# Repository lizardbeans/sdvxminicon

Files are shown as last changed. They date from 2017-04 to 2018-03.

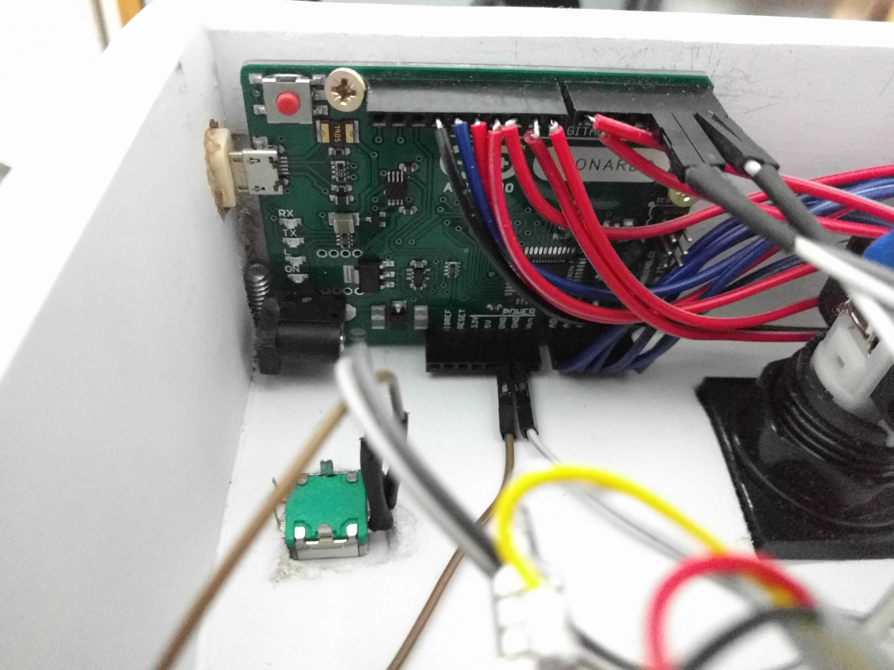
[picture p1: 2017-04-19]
img/027.jpg

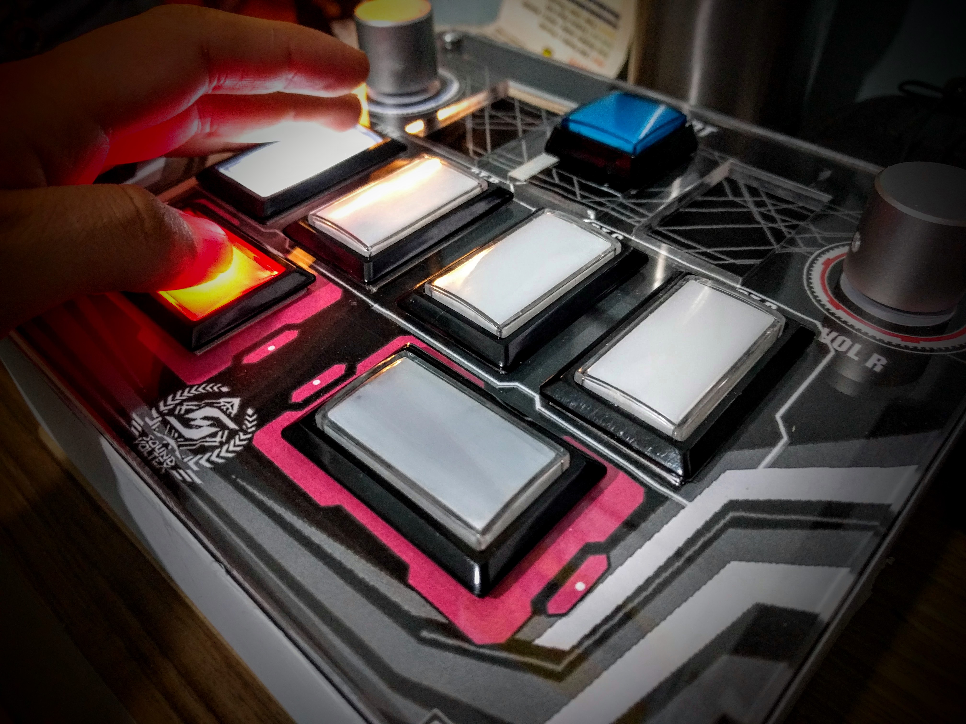
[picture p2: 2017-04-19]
img/032.jpg

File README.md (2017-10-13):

# sdvxminicon
**Instructions here: http://consandstuff.github.io/rhythmcons/sound-voltex/sdvx-minicon/**

Minicon Gallery http://imgur.com/a/BgS4V

The code is a modified version of this github repository:https://github.com/4yn/iivx

Upload using Arduino IDE 1.8.3

Tested only with 24ppr encoders.

## Part List

- 5mm laser cut clear acrylic $10-15
- 6pcs. 50x30mm chinese beatmania buttons $15 (led and switch included)
- 1pc. 30x30mm start buton $3 (led and switch included)
- 2pcs. cheap rotary encoder (24ppr) $10
- 2pcs. 22x20mm aluminum knobs $16
- 1pc. 50x50cm 5mm MDF plank (box walls) $2
- 1pc. 50x50cm 3mm MDF plank (box top and bottom door) $1
- 1pc. Arduino Leonardo PCB $18
- jumper wires pack $5
- 7pcs. crimp connectors $2 
- 2pcs. metal hinge $1 (for the door)
- 2pcs. magnetic lock $2 (for the door)
- 2pcs. 100 sandpaper $2
- 2pcs. 180 sandpaper $2

subtotal: $87

Want to change to SANWA buttons?
Add 6 12 dollar buttons instead of the chinese buttons.
Total: $144

Optional:
- 1pc. spray paint can $15 (matte white)

Tools:
- electric jigsaw
- electric sander
- electric drill

Skills:
- drilling- jigsaw-ing
- sanding
- soldering

**PIN LAYOUT (LEONARDO ARDUINO)**

<table><thead>
<tr>
<th>Button</th>
<th style="text-align: center">Pin #</th>
<th style="text-align: center">Button #</th>
<th style="text-align: center">LED Pin #</th>
</tr>
</thead><tbody>
<tr>
<td>Start</td>
<td style="text-align: center">13</td>
<td style="text-align: center">Button 1</td>
<td style="text-align: center">6</td>
</tr>
<tr>
<td>BT-A</td>
<td style="text-align: center">A0</td>
<td style="text-align: center">Button 2</td>
<td style="text-align: center">7</td>
</tr>
<tr>
<td>FX-L</td>
<td style="text-align: center">A1</td>
<td style="text-align: center">Button 3</td>
<td style="text-align: center">8</td>
</tr>
<tr>
<td>BT-B</td>
<td style="text-align: center">A2</td>
<td style="text-align: center">Button 4</td>
<td style="text-align: center">9</td>
</tr>
<tr>
<td>BT-C</td>
<td style="text-align: center">A3</td>
<td style="text-align: center">Button 5</td>
<td style="text-align: center">10</td>
</tr>
<tr>
<td>FX-R</td>
<td style="text-align: center">A4</td>
<td style="text-align: center">Button 6</td>
<td style="text-align: center">11</td>
</tr>
<tr>
<td>BT-D</td>
<td style="text-align: center">A5</td>
<td style="text-align: center">Button 7</td>
<td style="text-align: center">12</td>
</tr>
</tbody></table>

<table><thead>
<tr>
<th>ENCODERS</th>
<th style="text-align: center">DATA 1</th>
<th style="text-align: center">DATA 2</th>
</tr>
</thead><tbody>
<tr>
<td>Left knob (VOL-L)
<td style="text-align: center">0</td>
<td style="text-align: center">1</td>
</tr>
<tr>
<td>Right knob (VOL-R)
<td style="text-align: center">2</td>
<td style="text-align: center">3</td>
</tr>
</tbody></table>

>**If you're using 600ppr encoders you have to connect the encoders to the 5V pin for the 5v input (usually is the red wire)**

Any questions, troubleshooting or tips? Try my Discord server:

https://discord.gg/fknwz8s

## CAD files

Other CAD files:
cad/MINICON - Box.dwg
cad/MINICON - Acrylic 5mm.dwg

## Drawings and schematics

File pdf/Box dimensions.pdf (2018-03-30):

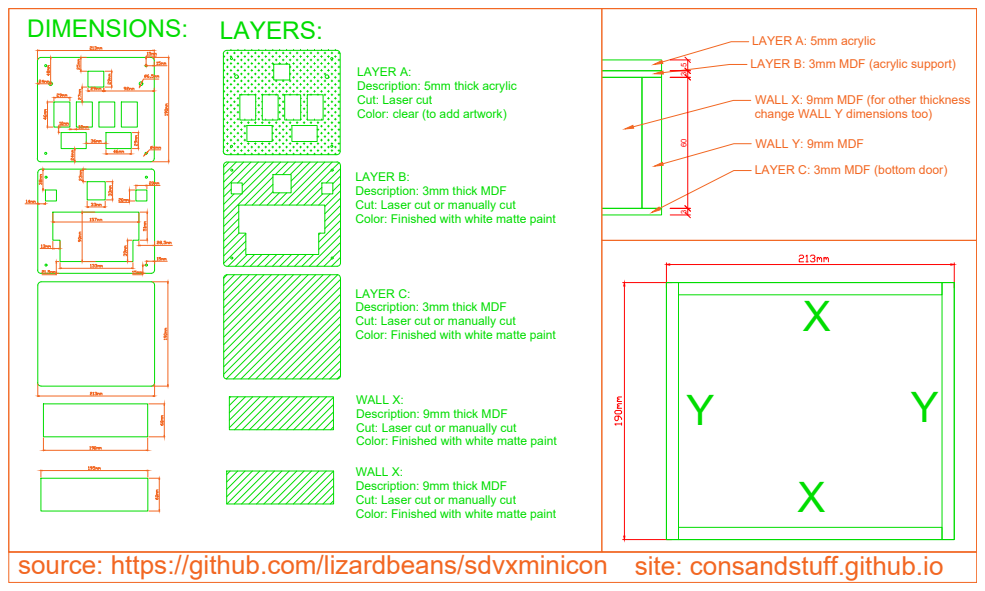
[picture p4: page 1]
LAYERS:; LAYER A: Description: 5mm thick acrylic Cut: Laser cut Color: clear (to add artwork) LAYER B: Description: 3mm thick MDF; Color: Finished with white matte paint DIMENSIONS:; LAYER A: 5mm acrylic LAYER B: 3mm MDF (acrylic support) WALL X: 9mm MDF (for other thickness change WALL Y dimensions too) WALL Y: 9mm MDF LAYER C: 3mm MDF (bottom door) 5 3 60 3 Y; Y XX source: https://github.com/lizardbeans/sdvxminicon site: consandstuff.github.io

Cut: Laser cut or manually cut
Color: Finished with white matte paint LAYER C: Description: 3mm thick MDF

Color: Finished with white matte paint WALL X: Description: 9mm thick MDF

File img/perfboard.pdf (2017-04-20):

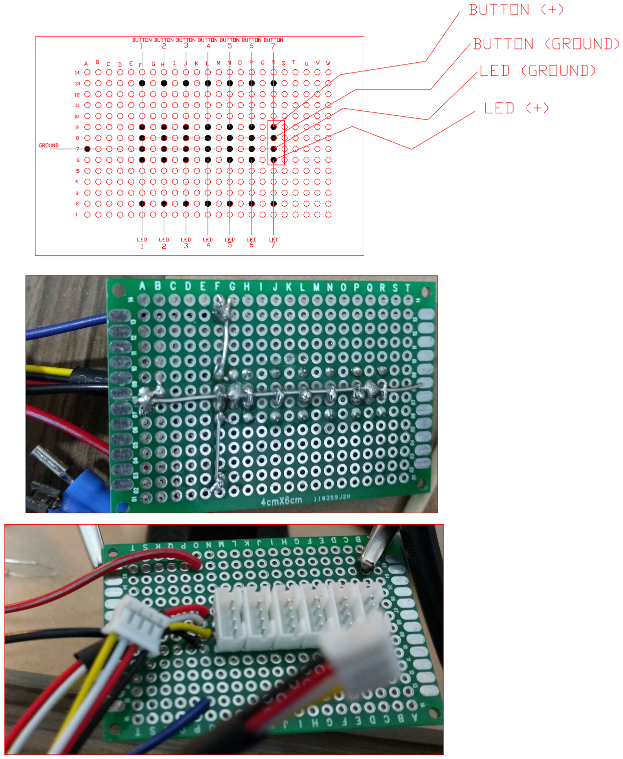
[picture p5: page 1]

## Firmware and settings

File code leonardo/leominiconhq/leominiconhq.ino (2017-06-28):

#include "iivx_leo.h"
iivxReport_t report; 

#define REPORT_DELAY 2000
// Number of microseconds between HID reports
// 2000 = 500hz

#define ENC_L_A 0
#define ENC_L_B 1
#define ENC_L_B_ADDR 3
#define ENC_R_A 2
#define ENC_R_B 3
#define ENC_R_B_ADDR 0
#define ENCODER_SENSITIVITY (double) 2.34375
#define ENCODER_PORT PIND
// encoder sensitivity = number of positions per rotation (600/256) / number of positions for HID report (256)
/*
 * connect encoders
 * VOL-L to pins 0 and 1
 * VOL-R to pins 2 and 3
 */

int tmp;
uint8_t buttonCount = 7;
uint8_t lightMode = 0;
// 0 = reactive lighting, 1 = HID lighting
uint8_t ledPins[] = {6,7,8,9,10,11,12};
uint8_t buttonPins[] = {13,18,19,20,21,22,23};
uint8_t sysPin = 5;
uint8_t reactiveLightPin = 21;
uint8_t hidLightPin = 22;
uint8_t sysInputPins[] = {13,18,19,20};
int32_t encL=0, encR=0;
/* current pin layout
 *  pins 6 to 12 = LED 1 to 7
 *  pins 13, A0 to A5 = Button input 1 to 7
 *  pins 5 = system pin
 *    connect system pin to ground with a small button
 *      press together with other buttons to change lighting scheme
 *    system button + button 1 = reactive lighting
 *    system button + button 3 = HID lighting
 */
 

void doEncL(){
  if((ENCODER_PORT >> ENC_L_B_ADDR)&1){
    encL++;
  } else {
    encL--;
  }
}

void doEncR(){
  if((ENCODER_PORT >> ENC_R_B_ADDR)&1){
    encR++;
  } else {
    encR--;
  }
}

void lights(uint8_t lightDesc){
  for(int i=0;i<buttonCount;i++){
     if((lightDesc>>i)&1){
         digitalWrite(ledPins[i],HIGH);
     } else {
         digitalWrite(ledPins[i],LOW);
     }
  }
}

void setup() {
  delay(1000);
  // Setup I/O for pins
  for(int i=0;i<buttonCount;i++){
    pinMode(buttonPins[i],INPUT_PULLUP);
    pinMode(ledPins[i],OUTPUT);
  }
  pinMode(sysPin,INPUT_PULLUP);
  //setup interrupts
  pinMode(ENC_L_A,INPUT_PULLUP);
  pinMode(ENC_L_B,INPUT_PULLUP);
  pinMode(ENC_R_A,INPUT_PULLUP);
  pinMode(ENC_R_B,INPUT_PULLUP);
  attachInterrupt(digitalPinToInterrupt(ENC_L_A), doEncL, RISING);
  attachInterrupt(digitalPinToInterrupt(ENC_R_A), doEncR, RISING);
}

void loop() {
  // Read buttons
  for(int i=0;i<buttonCount;i++){
    if(digitalRead(buttonPins[i])!=HIGH){
      report.buttons |= (uint16_t)1 << i;
    } else {
      report.buttons &= ~((uint16_t)1 << i);
    }
  }
  // Read Encoders
  report.xAxis = (uint8_t)((int32_t)(encL / ENCODER_SENSITIVITY) % 256);
  report.yAxis = (uint8_t)((int32_t)(encR / ENCODER_SENSITIVITY) % 256);
  // Light LEDs
  if(lightMode==0){
    lights(report.buttons);
  } else {
    lights(iivx_led);
  }
  // Detect Syspin Entries
  if(digitalRead(sysPin)!=HIGH){
    report.buttons = 0;
    for(int i=0;i<4;i++){
      if(digitalRead(sysInputPins[i])!=HIGH){
        report.buttons |= (uint16_t)1 << (i+buttonCount);
      } else {
        report.buttons &= ~((uint16_t)1 << (i+buttonCount));
      }
    }
    if(digitalRead(reactiveLightPin)!=HIGH){
      lightMode = 0;
    } else if (digitalRead(hidLightPin)!=HIGH){
      lightMode = 1;
    }
  }
  // Send report and delay
  iivx.setState(&report);
  delayMicroseconds(REPORT_DELAY);
}

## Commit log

2017-04-19 Added CAD files
    [MINICON - Acrylic 5mm.dwg, MINICON - Box.dwg]
2017-08-10 Fixed pin table
2018-03-30 Updated CAD files
    Changes the position for screws holes. Also updates the whole CAD file to understand better what has to be done.
    [MINICON - Acrylic 5mm.dwg, MINICON - Box.dwg]
2018-03-30 Added PDF instructions
    Added PDF file with instructions on mounting the different acrylic and MDF layers.
